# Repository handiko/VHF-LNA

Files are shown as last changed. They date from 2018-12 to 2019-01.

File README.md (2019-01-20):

# MMIC VHF Low Noise Amplifier
VHF Low Noise Amplifier Circuit &amp; PCB using common MMIC. This unit is capable up to 1kW at 2m-band (144 MHz) and powered by +12V supply thru a separate cable (hi-power bias tee is not implemented). MMIC input is protected by a BPF. Therefore, due to the BPF insertion loss, the input NF is not extremely good, (only 1 dB NF approx.). All the Eagle and Gerber files are included.

## Schematic
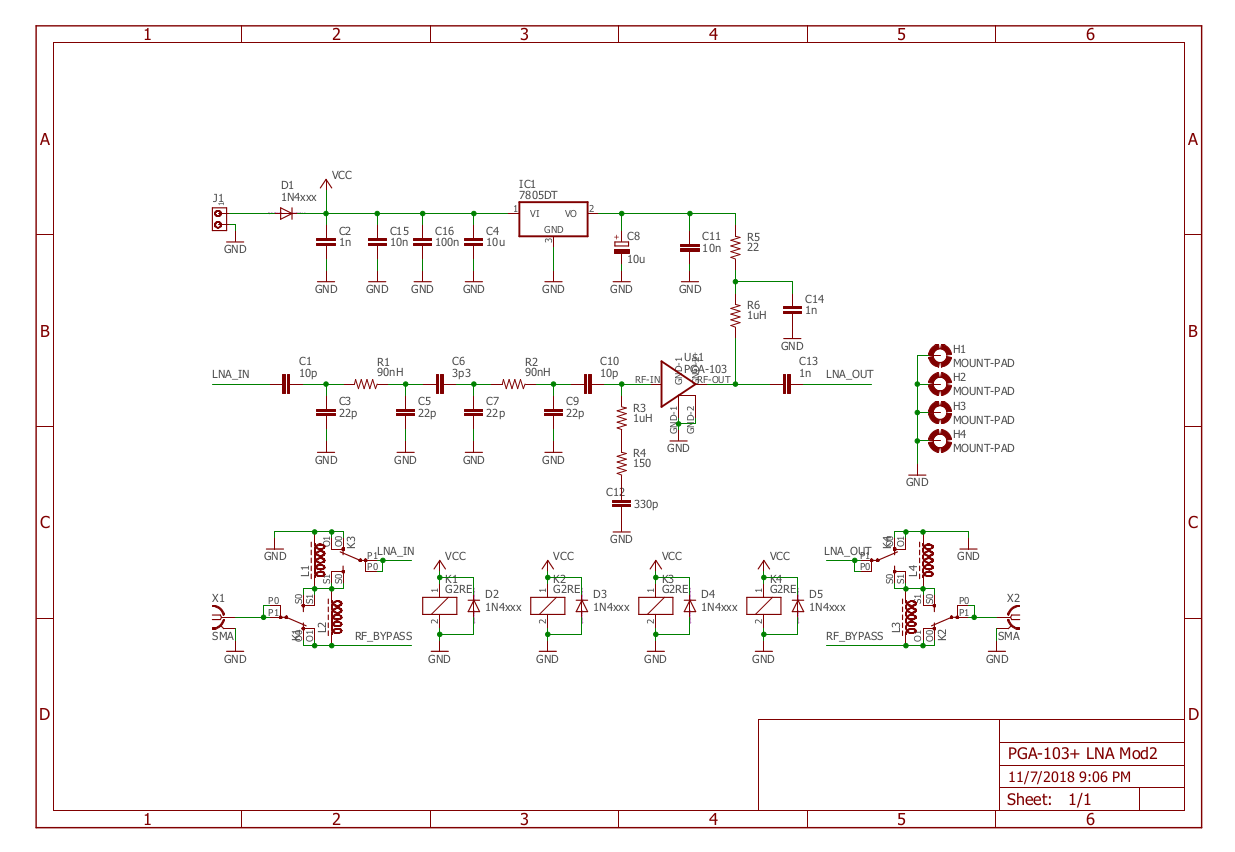
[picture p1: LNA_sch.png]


## PCB (photos)
* Unpopulated
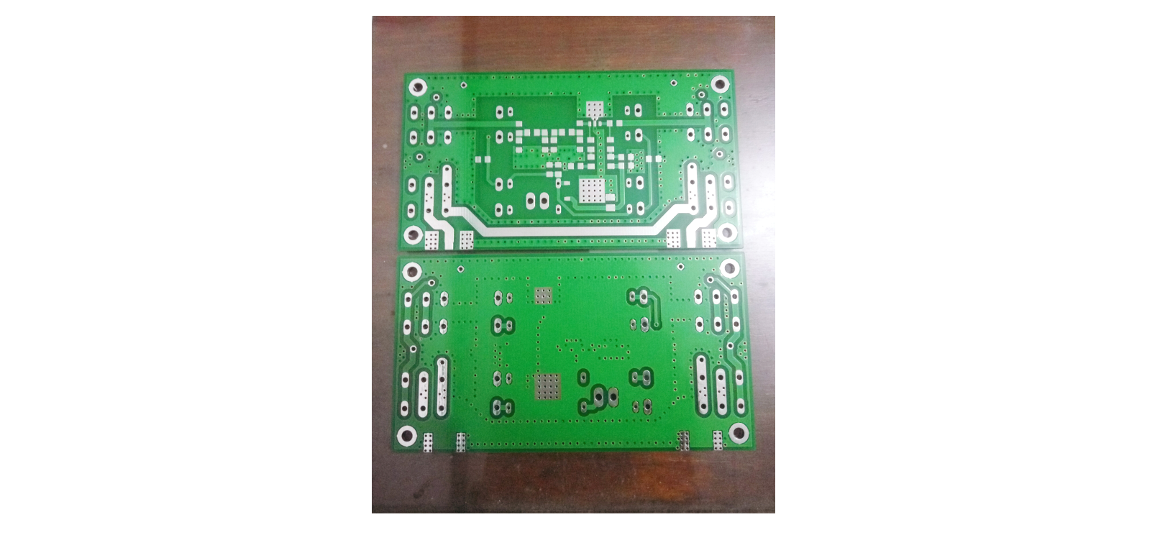
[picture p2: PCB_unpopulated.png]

* Populated. The input port is at near the lower right relay and the output port is at near the lower left relay.
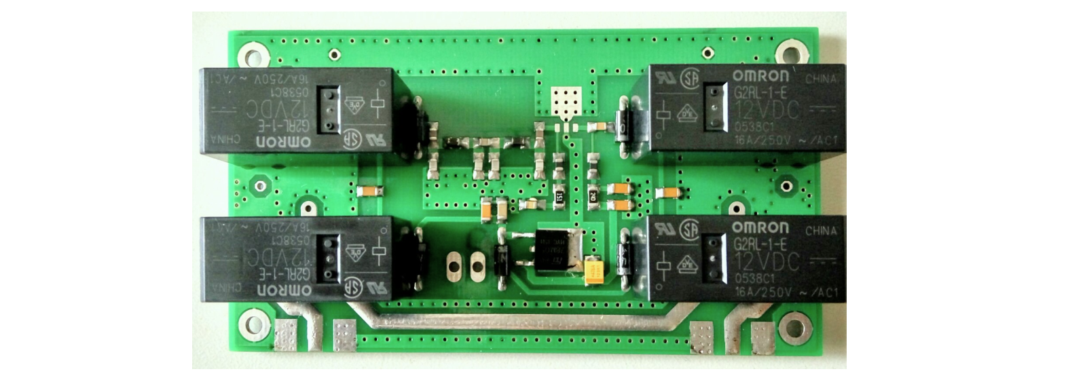
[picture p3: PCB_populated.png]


## BPF Response
BPF simulation file (using RFSim99) is included also.
Predicted performance:
* **S21 -3dB from 135.67MHz - 150.07MHz**
* **S21 -10dB from 131.1MHz - 154.5MHz**
* **S21 -0.02dB and S11 -23.86dB at 139.1MHz** (WXSat band)
* **S21 -0.31dB and S11 -11.59dB at 143.02MHz** (BPF Center Frequency)
* **S21 -0.21dB and S11 -13.17dB at 144.3MHz** (EME Band)
* **S21 -0.04dB and S11 -20.69dB at 145.8MHz** (2m AMSAT Band)
* **FM Broadcast band rejection is better than -28dB (S21) at 108MHz**

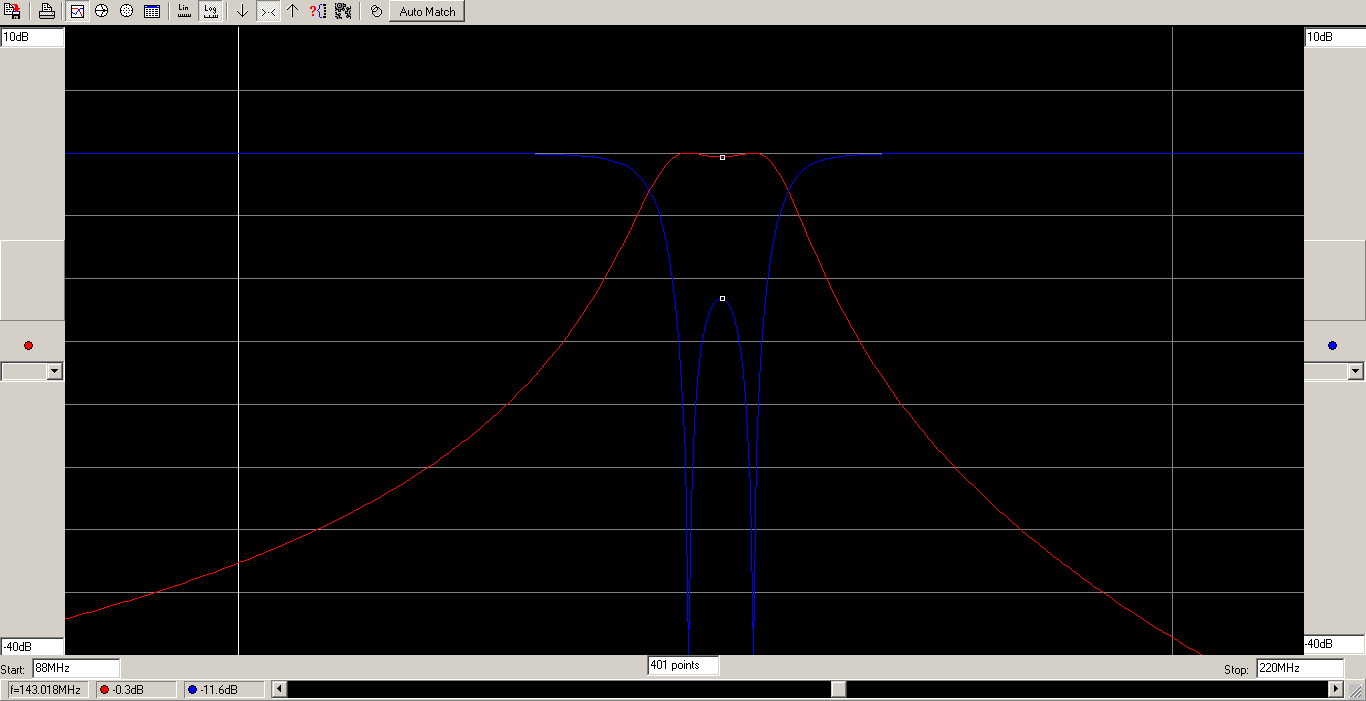
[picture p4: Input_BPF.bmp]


## Contributing
1. Fork it [https://github.com/handiko/VHF-LNA/fork](https://github.com/handiko/VHF-LNA/fork)
2. Create new branch (`git checkout -b add-blah-blah`)
3. Do some editing / create new feature
4. Commit your works (`git commit -m "Adding some blah blah blah.."`)
5. Push to the branch (`git push -u origin add-blah-blah`)
6. Create a new Pull Request

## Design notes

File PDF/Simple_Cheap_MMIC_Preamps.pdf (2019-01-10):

# Simple Cheap MMIC Preamps

## Who needs a GaAsFET?

## Paul Wade W1GHZ ©2014

w1ghz@arrl.net

I have tried some of the newer MMICs from Minicircuits¹

as moderate power amplifiers²,3 ,
providing several hundred milliwatts with good gain from VHF through the lower microwave bands. Noise figures (NF) are reasonable for a power amplifier, perhaps 4 dB, so the dynamic range is impressive.

At Microwave Update 2013, WA5VJB was selling LNA kits at a reasonable price – the kit consisted of a MMIC and a PC board. The PCB was marked G4DDK/G8EMY/VJB, two guys who know about LNA design, so I bought one to give it a try. The MMIC is a Minicircuits PGA-103. The datasheet shows NF under 1 dB from 50 MHz up to 2 GHz. I put the kit together and fired it up – the Noise Figure is under 1 dB at 144, 432, and 1296 MHz, all with no tuning. Gain is 22.5 dB at 144 MHz, 20 dB at 432 MHz, and 12 dB at 1296 MHz. Not bad for a $1.99 device!

The circuit, shown in Figure 1, is very simple, with just a blocking capacitor in and out, and an RF choke to supply 5 volts to the MMIC. The reason for the RF choke, unlike the resistor used in older MMICs, is that the current is rather high, about 100 milliamps, so the required resistor would be rather small, less than 10 ohms, which would substantially reduce the gain.

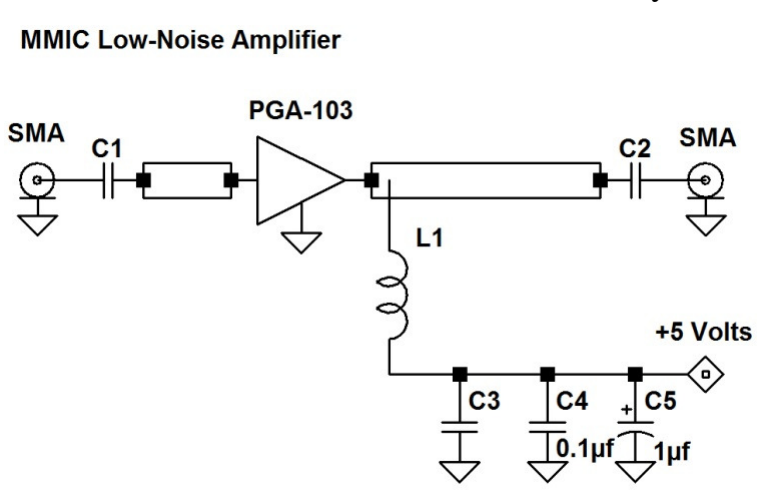
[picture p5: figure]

Figure 1- MMIC LNA Schematic Diagram

Frequency | C1 | C2 | C3 | L1 | Suggested L1 | Digikey
144 MHz | 1000 pf | 1000 pf | 1000pf | 56 nh | Bournes PM0805-56 | M8460CT-ND
432 | 100 | 100 | 100 | 56 | Bournes PM0805-56 | M8460CT-ND
1296 | 18 | 18 | 18 | 27 | Bournes PM0805-27 | M8456CT-ND
PHA-1 | 100 | 100 | 100 | 27or56 | Bournes PM0805- | M8640CT-ND

The WA5VJB PC board is intended to attach directly to small coax cables. This is probably adequate for VHF, but not for microwave use. I used short lengths of thin semi-rigid coax, shown in Figure 2, but it does not feel robust.

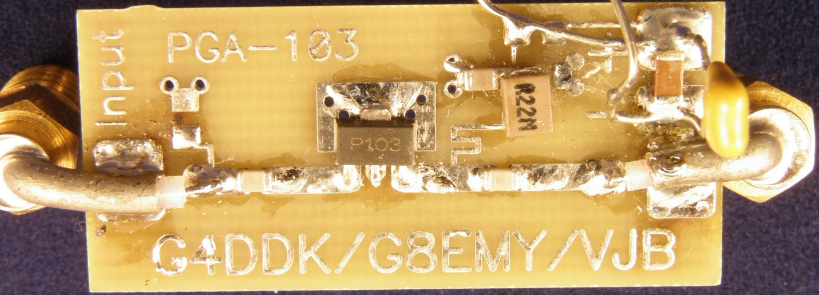
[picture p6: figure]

Figure 2 - MMIC Preamp on WA5VJB board

Since the simple circuit is similar to the moderate power amplifiers, I wanted to try some on the same PC boards I use for the power amplifiers. I ordered some PGA-103 MMICs, found some RF chokes in a sample kit from a VHF conference, and put three units together. I chose different component values for each unit: one to favor 144 MHz, one for 432 MHz, and one for 1296 MHz. One of these units is shown in Figure 3.

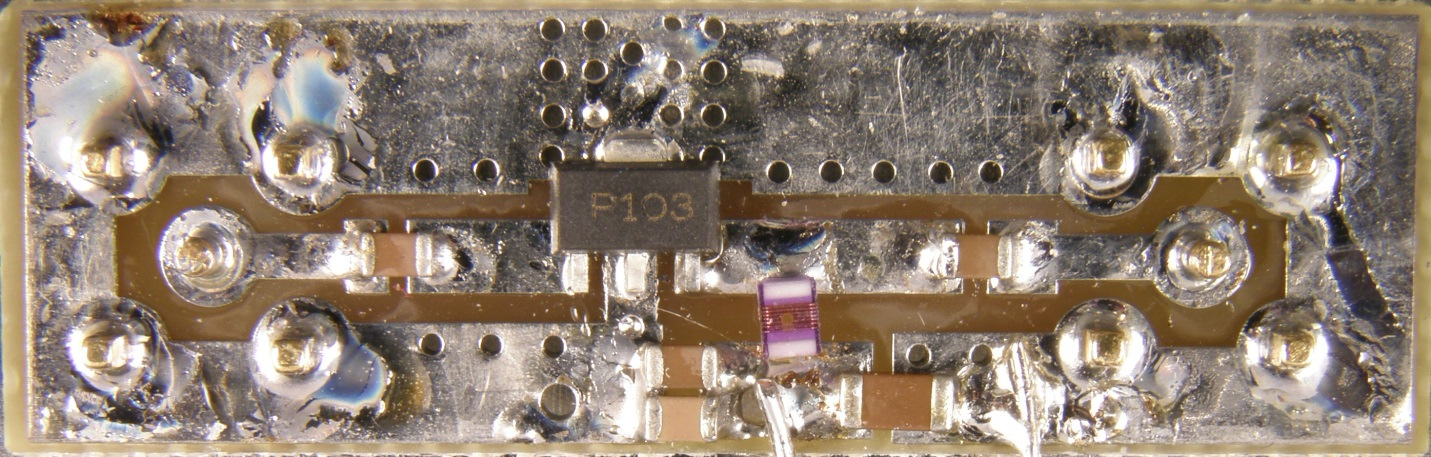
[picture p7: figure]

Figure 3 - MMIC preamp on PC board with SMA connectors

The 144 MHz unit had 26 dB of gain at 144, rolling off to 13 dB at 1296 MHz. Indicated Noise Figure was 0.25 dB at 144, 0.6 dB at 432, and 1.95 dB at 1296 MHz.

The 432 MHz unit had 25 dB of gain at 144, 21 dB at 432, rolling off to 13 dB at 1296 MHz. Indicated Noise Figure was 0.35 dB at 144, 0.6 dB at 432, and 1.7 dB at 1296 MHz.

The 1296 MHz unit had 19 dB of gain at 144, 22 dB at 270 MHz, 20 dB at 432, rolling off to 14 dB at 1296 MHz. Indicated Noise Figure was 0.65 dB at 144, 0.6 dB at 432, and 1.65 dB at 1296 MHz. Correcting for the second stage at 1296 gives a calculated device NF of about 0.75 dB. Using the 432 MHz unit as a second stage at 1296 MHz brought the indicated NF down to 0.75 dB.

At the recent 2014 Eastern VHF/UHF Conference, I got a chance to measure two units on modern, calibrated test equipment provided by Greg Bonaguide, WA1VUG, of Rohde & Schwarz. These units have the suggested component values for 144 MHz shown in Figure 1, packaged in an Altoids tin like Figure 6, with the internal voltage regulator shown in Figure 10. The results in Figure 4 confirm that the simple, inexpensive MMIC LNA has excellent performance up to at least the 2.3 GHz band.

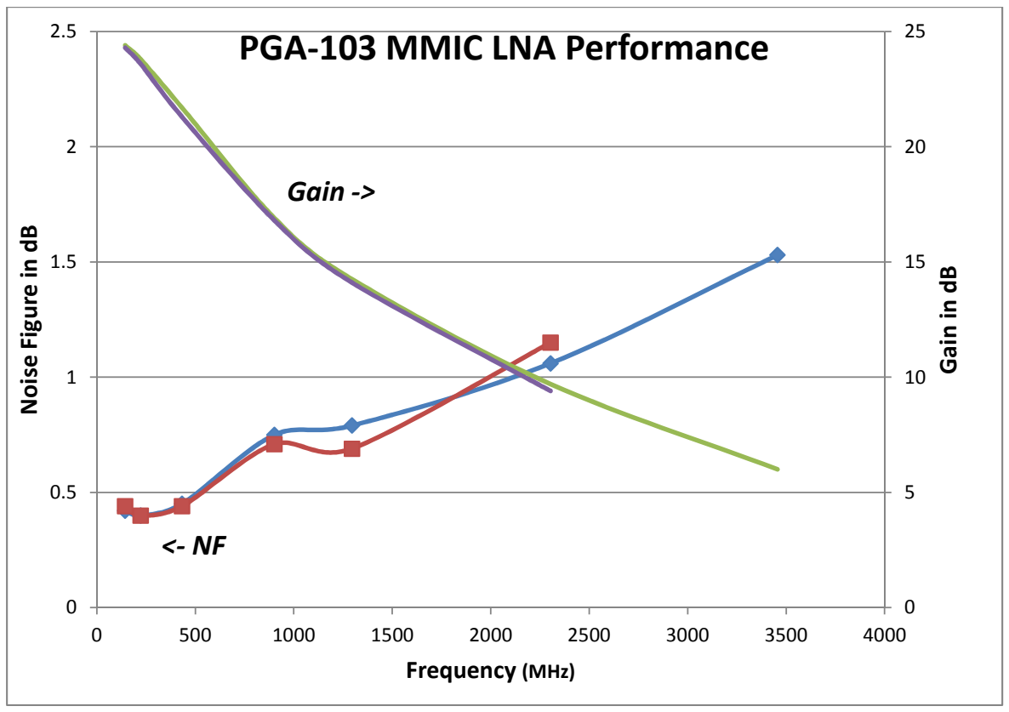
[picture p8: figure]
Gain in dB; Noise Figure in dB; Frequency (MHz); PGA-103 MMIC LNA Performance; Gain ->

Figure 4 – Measured performance of two MMIC LNAs

Another interesting MMIC is the Minicircuits PHA-1, also priced at $1.99. This device has lower gain, but pretty good noise figure and higher power capability, 200 milliwatts or so. The circuit is the same as Figure 1, and a PC board is shown in Figure 4. I tried a couple of these with the 1296 MHz component values. The gain is nearly flat at 15 dB, falling off slightly to about 13 dB at 1296 MHz. Noise Figure is also flat, about 2 dB at 144, 432, and1296 MHz. This one might be a good choice for a second stage.With appropriate component values, it might make a terrific 6-meter preamp with high dynamic range; most rigs don’t need a preamp at six meters, but some of the SDR rigs can use one.

Tuning

A really nice feature of these MMICs is that no tuning is required to get really good performance. The input and output are quite well matched, with Return Loss better than 10 dB over the whole frequency range, so tuning is probably not going to provide a whole lot of improvement.

Providing a low NF with a matched input is quite a contrast to a typical LNA, which might have an input reflection coefficient upward of 0.9 – highly mismatched – when tuned for best NF.
We know that a high VSWR increases transmission line loss; does this apply to the LNA as well? A low-VSWR MMIC with a slightly higher NF might reduce cable loss and provide better system performance than a mismatched LNA. EME operators know that putting the LNA right at the antenna eliminates transmission line loss and provides best performance.

Construction

These MMICs are in a small plastic SOT-89 package with three leads – the center lead is ground, and connects to a heatsink paddle on the bottom of the package. As
mentioned earlier, these devices draw roughly 100 mA at 5 Volts, so ½
watt is dissipated. Dead-bug construction will not work, heat sinking is
required. The PC boards have a number of plated-thru holes under the
ground lead and paddle to conduct the heat to the ground plane side of the
board. This seems adequate – the MMIC temperature is reasonable, according to one of my ten precision temperature sensors.

The MMIC and SMT components are soldered down with temperature-controlled soldering irons: first a hefty one for the device paddle and the SMA connectors, then a fine tip iron for the leads and other components. Figure 5 shows a unit under assembly in a precision fixture I made to hold the PC boards with SMA connectors attached during assembly.

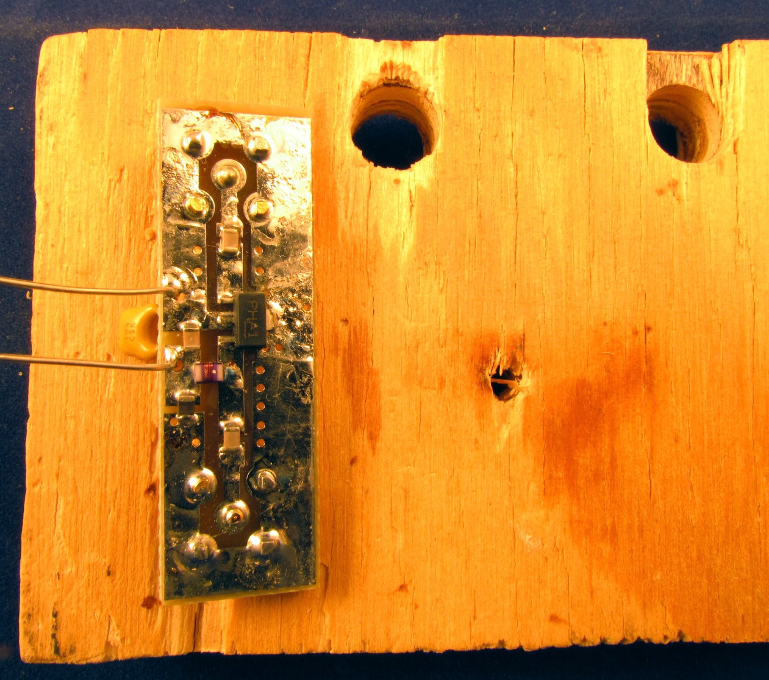
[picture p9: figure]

Figure 5 – PC board with PHA-1 MMIC in precision assembly fixture

Packaging

A plain PC board with SMA connectors like Figure 3 works just fine, but doesn’t offer much RF shielding or physical protection. For a small, inexpensive metal box, I found a small tin of Altoids mints at the Cabot General Store for $1.19 that is the perfect size. My first attempt at using these had the PC board inside the box and the SMA connector on the outside with the five SMA pins going through the box and board. The connector is soldered to the box and board. This required accurately drilling ten small holes as well as removing the paint from the Altoids tin.

After putting together a half-dozen or so preamps, I realized that the SMA connector cost was more than everything else combined. Time to look on ebay – I found some Chinese SMA connectors with a long threaded section for about a dollar each. These allow me to assemble and test the board before putting it in the box, and only two ¼ inch holes are required in the tin. Several of these preamps are shown in Figure 6. And the total cost of each preamp is under $10.

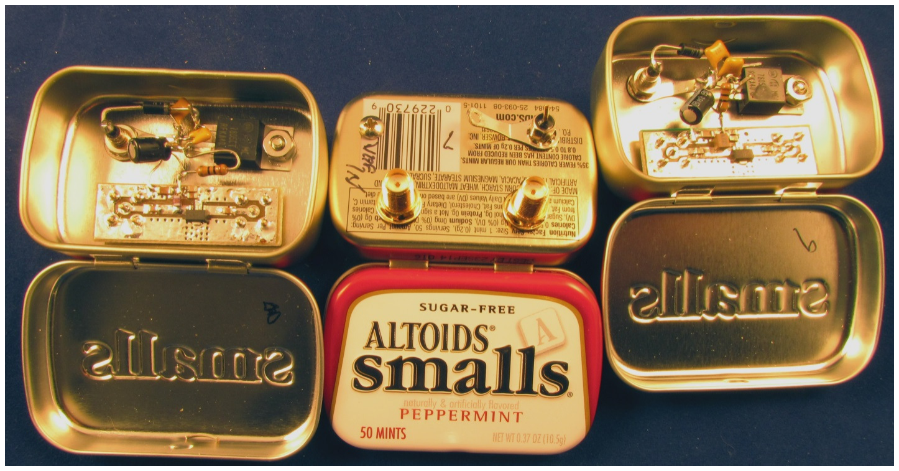
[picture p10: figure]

Figure 6 - MMIC preamps in small Altoids tin

Power Supply Noise

Since the MMICs operate at 5 volts, the obvious power solution is a three-terminal regulator. I added a 7805 regulator to a couple of the units and was surprised to find that the noise figure increased noticeably, from 0.25 dB to over 0.5 dB on the best unit. Some tests confirmed that the regulator was adding noise, and my oscilloscope showed about 8 millivolts of noise on the 5 volt regulator output.

I did some research and asked for suggestions on the internet microwave reflector. A few responses reminded me that the 7805 data sheet calls for capacitors on input and output – I’ve been using these things with the recommended capacitors for 40 years and have drawers full of the capacitors. But there were also some useful suggestions, which I appreciate, particularly a noise reduction circuit from Wenzel (http://www.wenzel.com/documents/finesse.html) and suggestions for zener diodes. I breadboarded and tried several different circuits to reduce the noise.

First, I looked at the Wenzel circuit and simulated it in LTSpice⁴
. It didn’t do diddlysquat to reduce noise. But companies like Wenzel like to run their oscillators at higher voltages, and the circuit works well at 15 volts. A bit of calculation and fiddling with component values yielded the circuit shown in Figure 7, which reduces noise on a 5-volt supply by more than 20 dB.

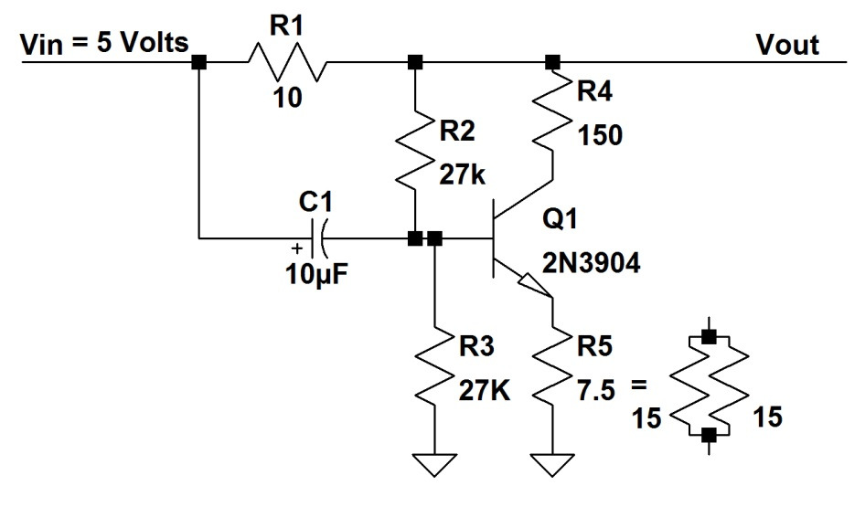
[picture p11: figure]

Figure 7 - Wenzel noise reduction circuit modified for 5 Volt operation

Another suggestion was the classic capacitance multiplier, shown in Figure 8.

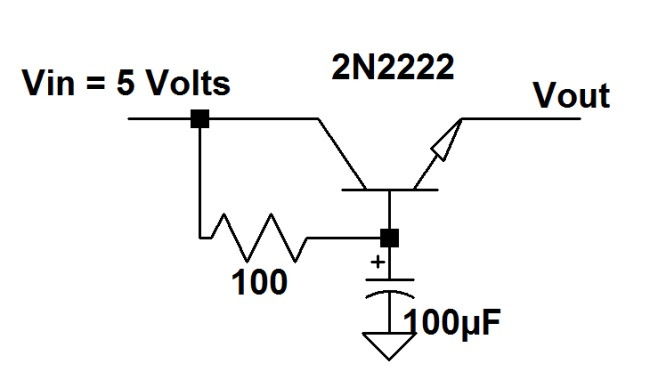
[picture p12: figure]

Figure 8 - Capacitance Multiplier for noise reduction

Zener diodes are often used in GaAsFET and HEMT preamps operating at low voltages, but those devices operate at much lower currents. (Zener is a misnomer – true zener diodes operate at 6 to 7 volts, while other voltages are really avalanche diodes, just like RF noise sources. The difference is that noise source diodes have very low capacitance, while power “zener” diodes have enough capacitance to limit noise at VHF and higher frequencies). For a 5 volt zener diode to provide 100 mA from a 12 volt battery (perhaps 11 to 15 volt range), a lot of power would be wasted in the zener and dropping resistor. However, most of my transverters operate on 8 volts from an internal regulator – having a fixed input voltage makes the zener practical, as shown in Figure 9, because we don’t have to waste as much current to allow for a wide input voltage range.

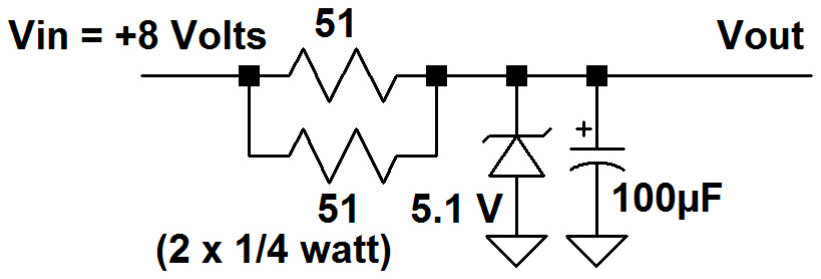
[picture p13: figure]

Figure 9 - Zener diode for 100 mA output

Finally, a simple resistor and capacitor following the three-terminal regulator, like Figure 10, may be adequate to reduce low-frequency noise. The RF decoupling capacitors should take care of higher frequencies.

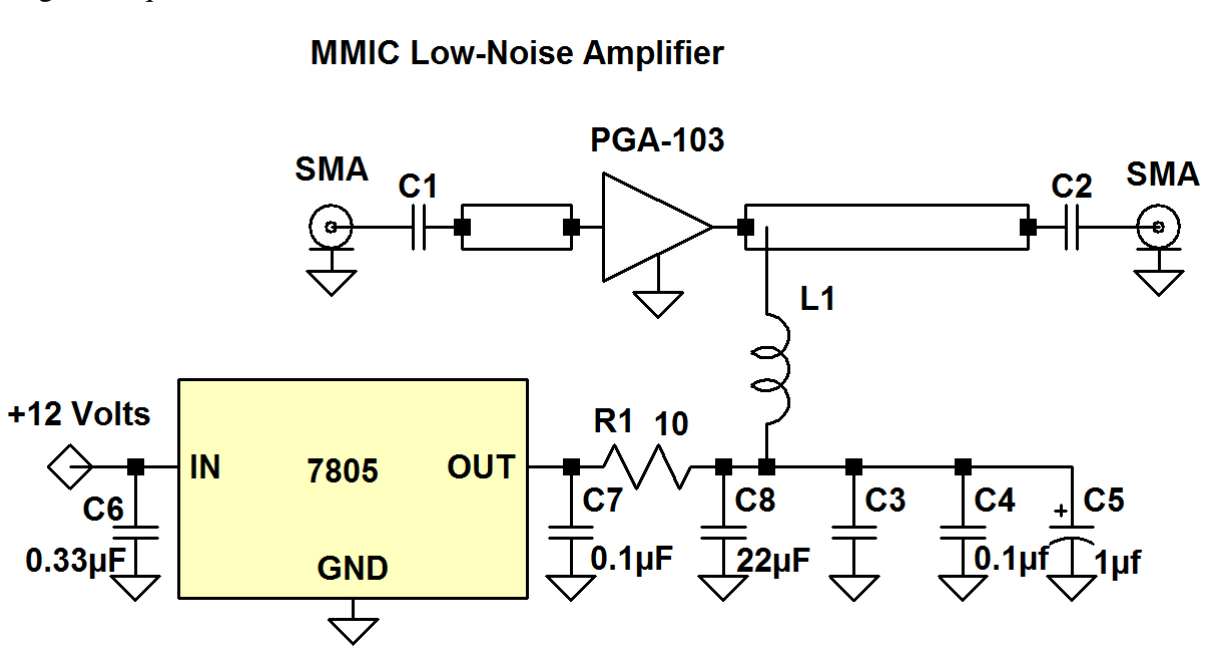
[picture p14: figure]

Figure 10 - Complete MMIC preamp schematic with simple R-C noise reduction

I breadboarded all of these noise reduction circuits and tried them on several preamps at both 144 and 432 MHz, testing the NF while powered with a battery for comparison. All of the circuits were successful in reducing the NF to the battery-powered level, so I wasn’t able to get any meaningful comparison. However, none of the preamps were as good as the original one with 0.25 dB NF – that one failed during the January VHF contest. I’d like to repeat the experiment with a really good one, but haven’t found another yet. For now, the simplest solution, following the 3-terminal regulator with the resistor and capacitor like Figure 10 seems to suffice. The resistor drops the voltage to around 4 volts, but the data sheet hints that NF may be better at lower voltage – I don’t see any appreciable difference.

Several complete preamps in small Altoids tins are shown in Figure 6. The regulator and noise reduction circuit is dead-bug wiring. Note that an idiot diode in series with the input voltage is missing from the schematic diagram, but included in each preamp.

Oscillations

After all the power supply experiments, when I tested all the units on the air with the VE2FUT 222 MHz beacon, I found that some of the units showed spurious responses on the FUncube dongle bandscope in Figure 11. Since they seem to have some relation with the beacon keying, my guess is a low frequency oscillation mixing with the beacon signal. The oscillations were still present with the preamp powered by a battery, so they are coming from the MMIC. The beacon signal is still weakly present, but should be ~40 dB out of the noise. These units also had about 10 dB more noise output than the other units. I don’t know why this oscillation didn’t show up on the noise figure meter, but on-the-air is what counts.

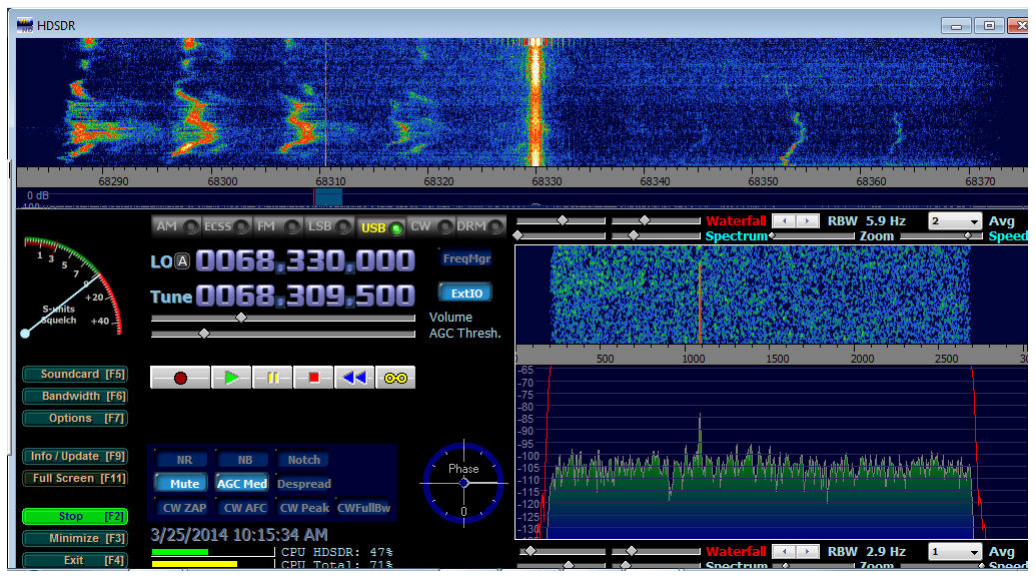
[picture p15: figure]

Figure 11 - Oscillating MMIC preamp listening to strong beacon

The oscillating units all had larger values of L1, 220 nh or 270 nh, chosen to be a high impedance at 144 MHz. The stable units have smaller L1, 30 or 51 nh, which appear to be wound with fine wire inside the surface mount inductor package; the winding is almost visible in Figure 3. Changing L1 to 51 nh tamed the oscillation. The inductor I use is Coilcraft 0805HQ-51NXJL from a sample kit – I haven’t found anywhere to buy these in small quantities. Some suggested alternatives are listed in Figure 1.

A screenshot after changing L1 is shown in Figure 12. I swung the beam to aim at the K2DLL 222 MHz beacon. The VE2FUT beacon is now off to the side, reducing the signal to about 15 dB out of the noise. This direction is close to most contest activity, so I can see beacons while watching the calling frequency – this is how I realized that my preamp had failed.

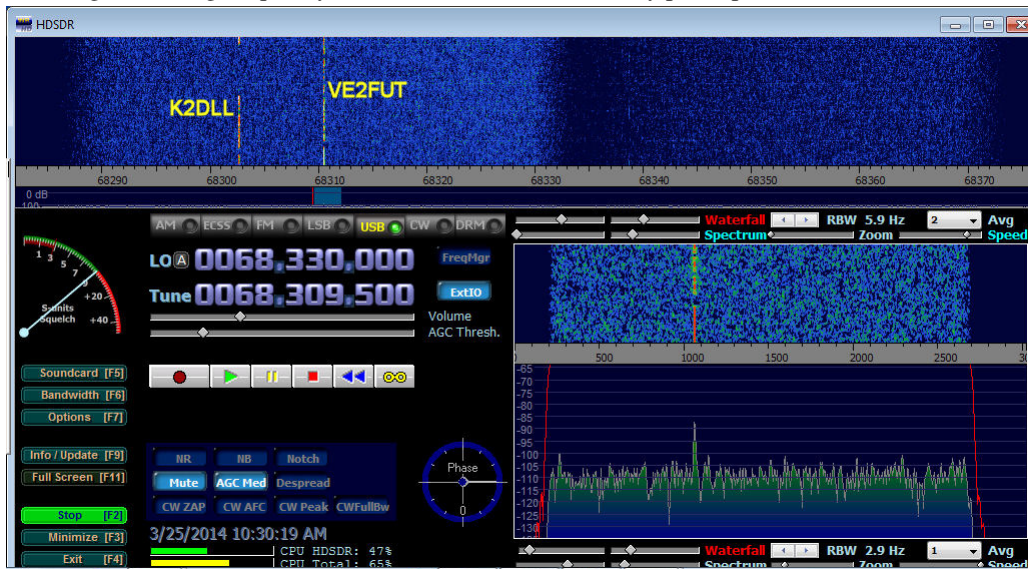
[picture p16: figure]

Figure 12 - Preamp after changing L1, receiving two beacons

Power supply noise can also increase phase noise in oscillators. Phase noise is insidious – we don’t notice its effect on weak signals, and it is hard to measure. So adding some of these noise reduction circuits to oscillators might help, and certainly can’t hurt.

Filters

These preamps are really broadband, totally untuned, with high gain – they amplify everything. For instance, the strongest FM broadcast station at my QTH, at 107.9 MHz, is -17 dBm on an FM turnstile antenna. Amplified by 25 dB, this is enough power to make the mixer in a transverter seriously upset. And there are many other FM, TV, and pager transmitters that are also line of sight. Selectivity of the ham antenna and the receiver helps, but a filter for each ham band significantly reduces the birdie count. See the accompanying filter articles for some suggestions.

One advantage of well-matched preamps like these is that the filter response will not be upset and the filter will perform as expected. Many filters are seriously affected by high VSWR or high Q at the input or output – we don’t usually measure this, but sometimes don’t get the performance we expect from a filter.

Summary

These MMICs make a great LNA which is simple, cheap, and easy to build. Putting one in front of a pretty good transverter makes the band really come alive. Performance is not quite as good as the best HEMT LNAs, but close enough for all terrestrial work and for EME below 432 MHz, frequencies where atmospheric and local noise is the limiting factor. Even for EME on the higher bands, these preamps would make a great second stage.

A real test is watching a beacon signal just above the noise pop right up on the bandscope when the preamp is added, in Figure 12. The signal strength jumps up more than 20 dB, so it sounds impressive. More important is that the bandscope shows several dB improvement in signal-to-noise ratio – that’s what counts, and makes a difference for copying weak signals

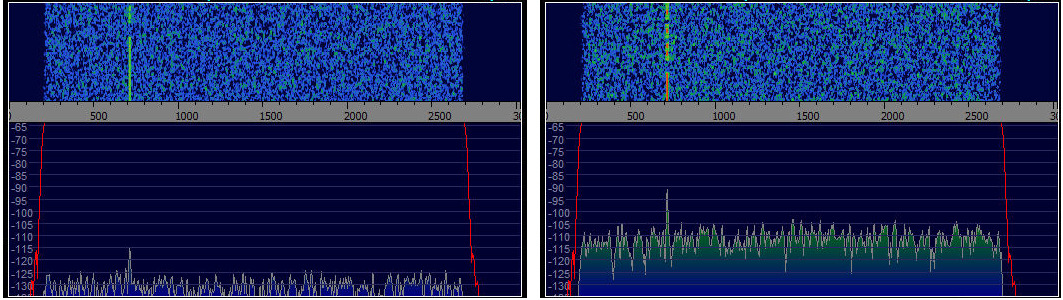
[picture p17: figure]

Figure 13 – Bandscope display without preamp on left, with preamp on right

I’ve made a dozen or so of these preamps, and all work well, with NF under 1 dB. This is a large enough sample size that you can expect similar results with no tuning. Only an hour or so is required for assembly and packaging, and the cost is low, around $10 if you buy everything.
I’d suggest building several so you have ready spares for roving, experiments, or even in case of a failure. When one of mine failed during the January VHF contest, I was able to swap it out in a couple of minutes.

So who needs a GaAsFET? No one, these MMICs are at least as good. Some of the HEMT devices might be better, but it only matters for EME or for bragging rights at NF competitions.

References
1. www.minicircuits.com
2. Paul Wade, W1GHZ, “A Modest Power Amplifier for Cheap and Simple Microwave Transverters,” Proceedings of the 46th Conference of the Central States VHF Society, ARRL, 2012, pp. 121-122.
3. Paul Wade, W1GHZ, “ADL5324 Power Amplifier for Cheap and Simple Microwave Transverters,” http://www.w1ghz.org/small_proj/ADL5324_Power_Amplifier.pdf
4. www.linear.com

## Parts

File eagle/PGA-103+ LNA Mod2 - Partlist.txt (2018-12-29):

Partlist

Exported from PGA-103+ LNA Mod2.sch at 11/7/2018 9:07 PM

EAGLE Version 7.7.0 Copyright (c) 1988-2016 CadSoft

Assembly variant: 

Part     Value          Device               Package                  Library         Sheet

C1       10p            C-EUC1206            C1206                    rcl             1
C2       1n             C-EUC1206            C1206                    rcl             1
C3       22p            C-EUC1206            C1206                    rcl             1
C4       10u            C-EUC1206            C1206                    rcl             1
C5       22p            C-EUC1206            C1206                    rcl             1
C6       3p3            C-EUC1206            C1206                    rcl             1
C7       22p            C-EUC1206            C1206                    rcl             1
C8       10u            CPOL-EUB/3528-21R    B/3528-21R               rcl             1
C9       22p            C-EUC1206            C1206                    rcl             1
C10      10p            C-EUC1206            C1206                    rcl             1
C11      10n            C-EUC1206            C1206                    rcl             1
C12      330p           C-EUC1206            C1206                    rcl             1
C13      1n             C-EUC1206            C1206                    rcl             1
C14      1n             C-EUC1206            C1206                    rcl             1
C15      10n            C-EUC1206            C1206                    rcl             1
C16      100n           C-EUC1206            C1206                    rcl             1
D1       1N4xxx         1N4148DO35-7         DO35-7                   diode           1
D2       1N4xxx         1N4148DO35-7         DO35-7                   diode           1
D3       1N4xxx         1N4148DO35-7         DO35-7                   diode           1
D4       1N4xxx         1N4148DO35-7         DO35-7                   diode           1
D5       1N4xxx         1N4148DO35-7         DO35-7                   diode           1
H1       MOUNT-PAD      MOUNT-PAD-ROUND2.8   2,8-PAD                  holes           1
H2       MOUNT-PAD      MOUNT-PAD-ROUND2.8   2,8-PAD                  holes           1
H3       MOUNT-PAD      MOUNT-PAD-ROUND2.8   2,8-PAD                  holes           1
H4       MOUNT-PAD      MOUNT-PAD-ROUND2.8   2,8-PAD                  holes           1
IC1      7805DT         7805DT               TO252                    linear          1
J1                      MTA02-156            1X2MTA                   con-amp         1
K1       G2RE           G2RE                 G2RE                     relay           1
K2       G2RE           G2RE                 G2RE                     relay           1
K3       G2RE           G2RE                 G2RE                     relay           1
K4       G2RE           G2RE                 G2RE                     relay           1
L1                      Z28/70CW             Z28/7                    inductor-neosid 1
L2                      Z28/70CW             Z28/7                    inductor-neosid 1
L3                      Z28/70CW             Z28/7                    inductor-neosid 1
L4                      Z28/70CW             Z28/7                    inductor-neosid 1
R1       90nH           R-US_M1206           M1206                    rcl             1
R2       90nH           R-US_M1206           M1206                    rcl             1
R3       1uH            R-US_M1206           M1206                    rcl             1
R4       150            R-US_M1206           M1206                    rcl             1
R5       22             R-US_M1206           M1206                    rcl             1
R6       1uH            R-US_M1206           M1206                    rcl             1
U$1      PGA-103        PGA-103              DF782                    minicircuits    1
X1       SMA            SMA-142-0701-851/861 J502-ND-142-0701-851/861 con-coax        1
X2       SMA            SMA-142-0701-851/861 J502-ND-142-0701-851/861 con-coax        1

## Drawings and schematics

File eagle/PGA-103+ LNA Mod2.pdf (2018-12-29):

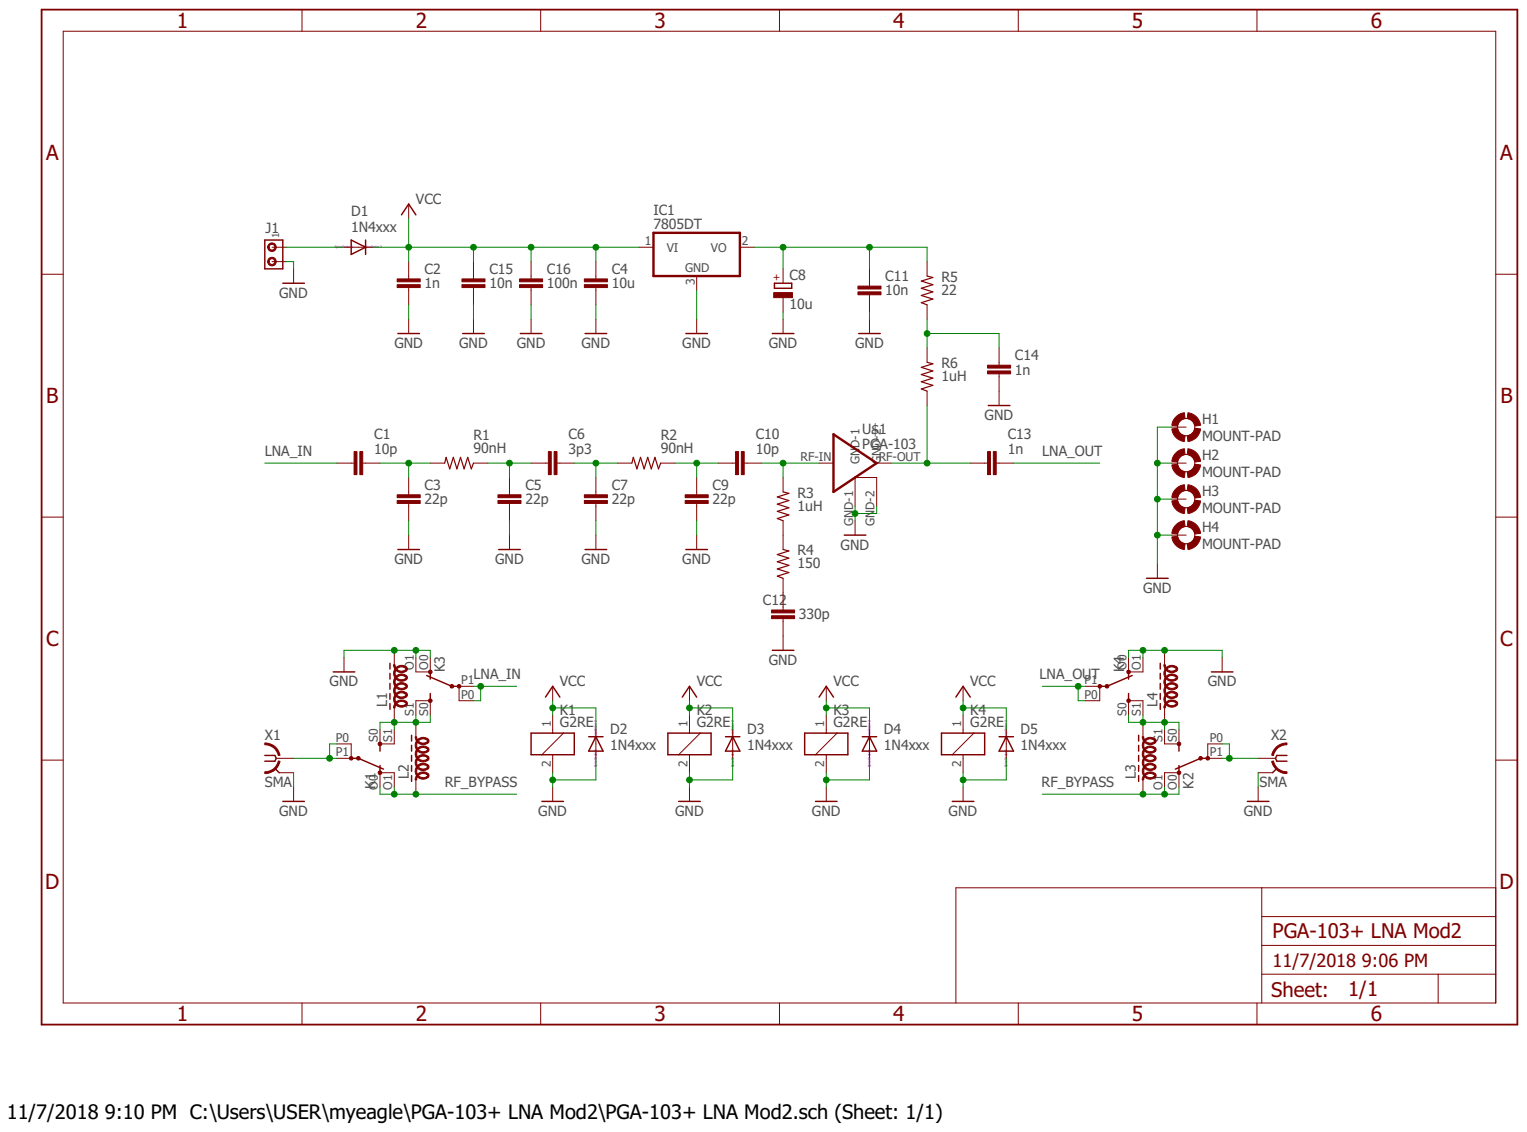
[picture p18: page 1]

11/7/2018 9:10 PM C:\Users\USER\myeagle\PGA-103+ LNA Mod2\PGA-103+ LNA Mod2.sch (Sheet: 1/1)

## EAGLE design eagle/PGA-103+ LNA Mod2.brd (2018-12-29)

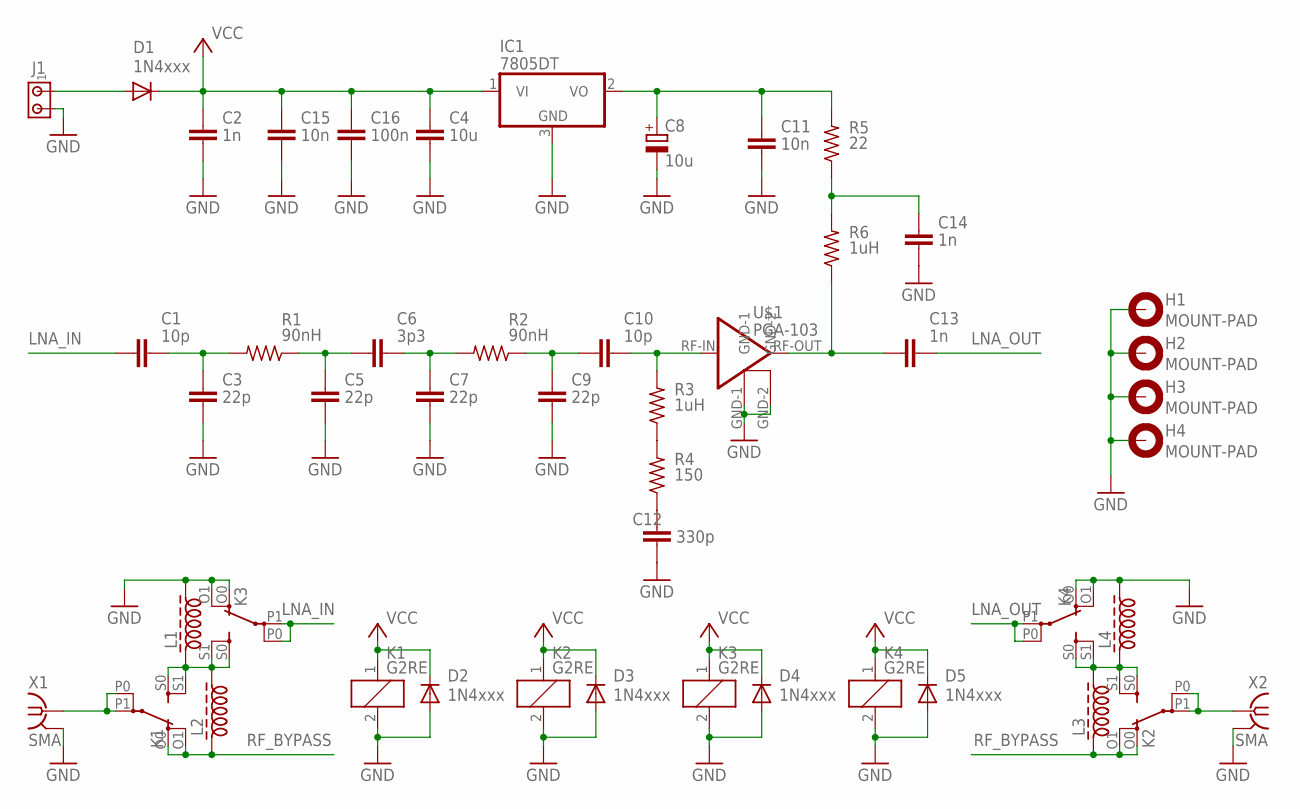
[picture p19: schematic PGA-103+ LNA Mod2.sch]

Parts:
C1, C10: 10p; C1206
C2, C13, C14: 1n; C1206
C3, C5, C7, C9: 22p; C1206
C4: 10u; C1206
C6: 3p3; C1206
C8: 10u; B/3528-21R
C11, C15: 10n; C1206
C12: 330p; C1206
C16: 100n; C1206
D1, D2, D3, D4, D5: 1N4xxx; DO35-7
H1, H2, H3, H4: MOUNT-PAD; 2,8-PAD
IC1: 7805DT; TO252
J1: MTA02-156; 1X2MTA
K1, K2, K3, K4: G2RE
L1, L2, L3, L4: Z28/70CW; Z28/7
R1, R2: 90nH; M1206
R3, R6: 1uH; M1206
R4: 150; M1206
R5: 22; M1206
U$1: PGA-103; DF782
X1, X2: SMA; J502-ND-142-0701-851/861

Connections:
ANT: K1.P0, K1.P1, X1.1
GND: C2.2, C3.1, C4.2, C5.1, C7.1, C8.-, C9.1, C11.2, C12.1, C14.1, C15.2, C16.2, D2.A, D3.A, D4.A, D5.A, H1.B2,8, H2.B2,8, H3.B2,8, H4.B2,8, IC1.3 (GND), J1.2, K1.2, K2.2, K3.2, K3.O0 (O), K3.O1 (O), K4.2, K4.O0 (O), K4.O1 (O), L1.2, L4.2, U$1.GND-1, U$1.GND-2, X1.G@1 (2), X1.G@2 (2), X1.G@3 (2), X1.G@4 (2), X2.G@1 (2), X2.G@2 (2), X2.G@3 (2), X2.G@4 (2)
LNA_IN: C1.1, K3.P0, K3.P1
LNA_OUT: C13.2, K4.P0, K4.P1
unnamed: C10.2, R3.2, U$1.RF-IN
unnamed: C13.1, R6.1, U$1.RF-OUT
unnamed: C8.+, C11.1, IC1.2 (VO), R5.2
unnamed: D1.A, J1.1
unnamed: C9.2, C10.1, R2.1
unnamed: C14.2, R5.1, R6.2
unnamed: R3.1, R4.2
unnamed: C12.2, R4.1
unnamed: C6.2, C7.2, R2.2
unnamed: C5.2, C6.1, R1.1
unnamed: C1.2, C3.2, R1.2
unnamed: K1.S0 (S), K1.S1 (S), K3.S0 (S), K3.S1 (S), L1.1, L2.2
unnamed: K2.S0 (S), K2.S1 (S), K4.S0 (S), K4.S1 (S), L3.2, L4.1
RF_BYPASS: K1.O0 (O), K1.O1 (O), K2.O0 (O), K2.O1 (O), L2.1, L3.1
TRX: K2.P0, K2.P1, X2.1
VCC: C2.1, C4.1, C15.1, C16.1, D1.C, D2.C, D3.C, D4.C, D5.C, IC1.1 (VI), K1.1, K2.1, K3.1, K4.1

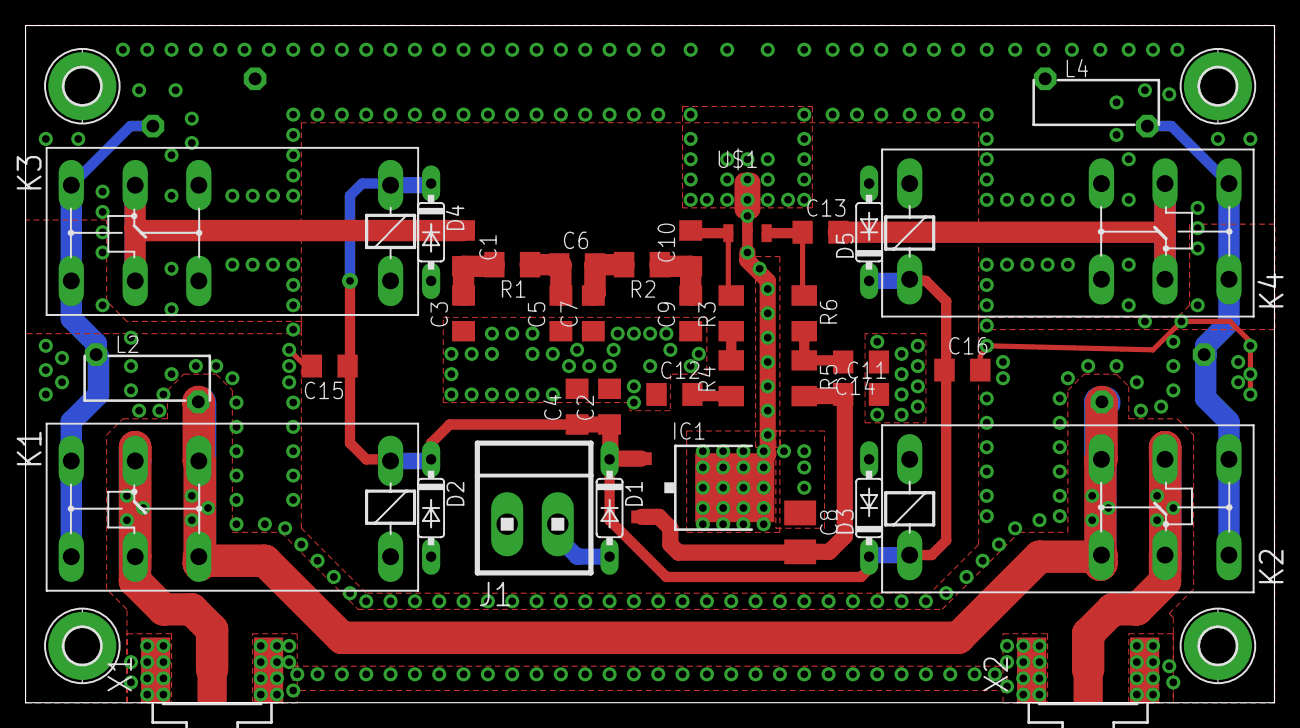
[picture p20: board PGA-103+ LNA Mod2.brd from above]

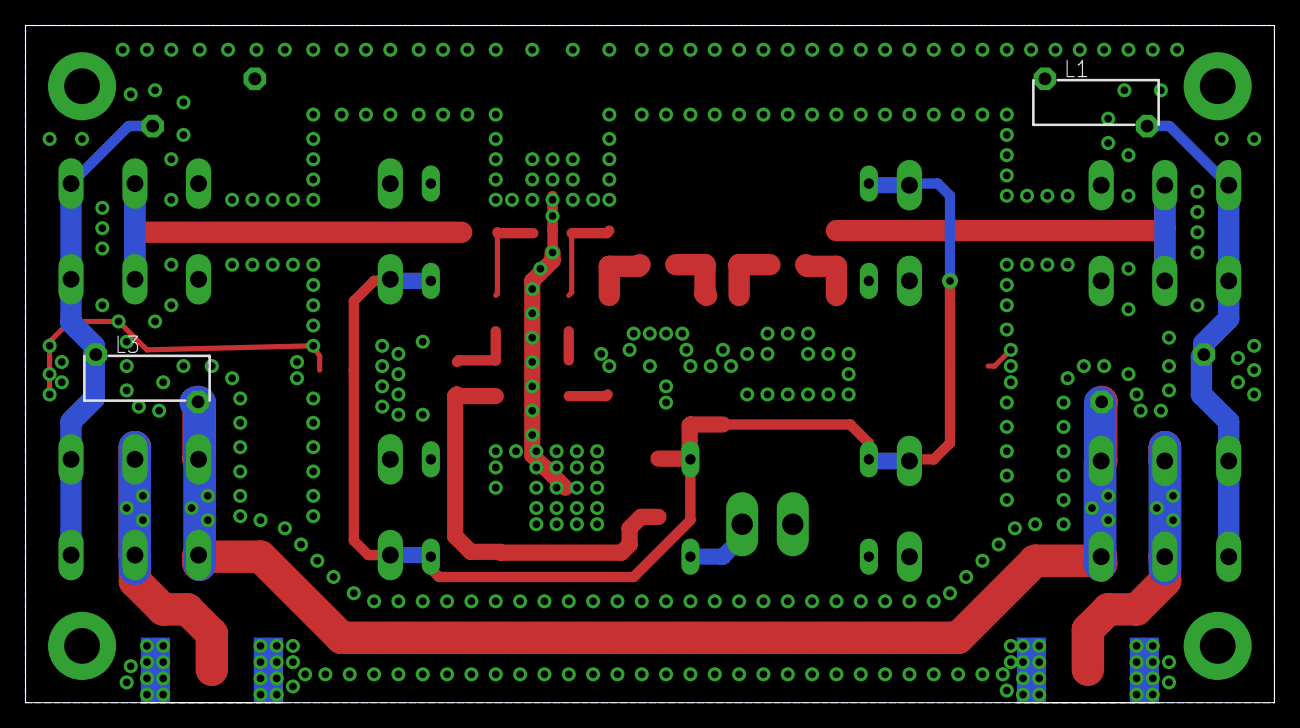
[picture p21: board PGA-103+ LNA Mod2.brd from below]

Board: 2 copper layers, 97.8 x 53.0 mm, 44 parts (2 on the bottom side), 20 nets.
